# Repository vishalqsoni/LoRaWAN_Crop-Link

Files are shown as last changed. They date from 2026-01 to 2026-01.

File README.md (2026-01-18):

# LoRaWAN_Crop-Link
Crop Link is a LoRa-based IoT data logging and communication system designed for reliable sensor data transmission from remote agricultural fields to the cloud Using LoRaWAN. The system operates independently of GSM or cellular networks.
Screenshot 2026-01-18 at 4 59 33 PM

6F46C575-3EEC-48E3-9C0B-685C3D67DB7D_1_201_a
B4C97D39-0B5F-4EE4-A005-456987E007A9_1_201_a
4F228DE5-FEAE-462C-B5F8-36705A7806EC_1_201_a
C9FC567B-2788-4EFA-AF8E-49FA644E9284_1_201_a
Yes, this project is open source. The circuit contains some mistakes, as this is version 1.1.2, so please do not blindly follow the schematic. For detailed information and updates, please visit my Hackster page.
https://www.hackster.io/iwantmyspace2002/the-crop-link-25cf29

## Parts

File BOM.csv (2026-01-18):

Reference | Qty | Value | DNP | Exclude from BOM | Exclude from Board | Footprint | Datasheet
BT1 | 1 | 18650_cell_holder |  |  |  | LoRa_Link:18650_cell_holder
C1,C2 | 2 | 10 uf C_Polarized |  |  |  | Capacitor_SMD:CP_Elec_4x5.4 | ~
C3,C4,C8,C9,C10,C11 | 6 | 4.7uf |  |  |  | Capacitor_SMD:C_0603_1608Metric | ~
C5 | 1 | 470nf |  |  |  | Capacitor_SMD:C_0603_1608Metric | ~
C6 | 1 | 220nf |  |  |  | Capacitor_SMD:C_0603_1608Metric | ~
C7 | 1 | 100nf |  |  |  | Capacitor_SMD:C_0603_1608Metric | ~
D1 | 1 | 3407A MOSFet |  |  |  | Package_TO_SOT_SMD:SOT-23 | https://www.littelfuse.com/~/media/electronics/datasheets/tvs_diode_arrays/littelfuse_tvs_diode_array_sm712_datasheet.pdf.pdf
D2,D3 | 2 | SS34 |  |  |  | Diode_SMD:D_SMA | https://www.vishay.com/docs/88751/ss32.pdf
D4 | 1 | CHAR |  |  |  | LED_SMD:LED_0603_1608Metric_Pad1.05x0.95mm_HandSolder | ~
D5 | 1 | Done |  |  |  | LED_SMD:LED_0603_1608Metric_Pad1.05x0.95mm_HandSolder | ~
H1,H2,H3,H4 | 4 | MountingHole |  |  |  | MountingHole:MountingHole_2.5mm | ~
J1 | 1 | 1.205volt |  |  |  | Connector_PinHeader_2.54mm:PinHeader_1x02_P2.54mm_Vertical | ~
J2 | 1 | UART1 |  |  |  | Connector_PinHeader_2.54mm:PinHeader_1x04_P2.54mm_Vertical | ~
J3 | 1 | UART0 |  |  |  | Connector_PinHeader_2.54mm:PinHeader_1x04_P2.54mm_Vertical | ~
J4 | 1 | 2171790001 |  |  |  | Connector_USB:USB_C_Receptacle_GCT_USB4105-xx-A_16P_TopMnt_Horizontal | https://www.molex.com/en-us/products/part-detail-pdf/2171790001?display=pdf
J5 | 1 | Conn_01x07_Female |  |  |  | Connector_PinHeader_2.54mm:PinHeader_1x07_P2.54mm_Vertical | ~
J6 | 1 | MJ-179PH |  |  |  | LoRa_Link:12Volt_Socket
J7,J8,J9,J10 | 4 | Conn_01x02 |  |  |  | Capacitor_SMD:C_0201_0603Metric | ~
J11 | 1 | Conn_01x06_Female |  |  |  | Connector_PinHeader_2.54mm:PinHeader_1x06_P2.54mm_Vertical | ~
J12 | 1 | flash |  |  |  | Connector_PinHeader_2.54mm:PinHeader_1x05_P2.54mm_Vertical | ~
J13 | 1 | Conn_01x03_Female |  |  |  | Connector_PinHeader_2.54mm:PinHeader_1x03_P2.54mm_Vertical | ~
J14 | 1 | 532530470 |  |  |  | Connector_PinHeader_2.54mm:PinHeader_1x04_P2.54mm_Vertical
J15 | 1 | Conn_01x04_Female |  |  |  | Connector_PinHeader_2.54mm:PinHeader_1x04_P2.54mm_Vertical | ~
J16 | 1 | Conn_01x05_Female |  |  |  | Connector_PinHeader_1.27mm:PinHeader_1x05_P1.27mm_Vertical | ~
J17 | 1 | Conn_01x04_Male POWER |  |  |  | Connector_PinHeader_2.54mm:PinHeader_1x04_P2.54mm_Vertical | ~
L1 | 1 | 47uh |  |  |  | Inductor_SMD:L_Coilcraft_MSS1210-XXX | ~
R1,R10,R11 | 3 | 10K |  |  |  | Resistor_SMD:R_0603_1608Metric_Pad0.98x0.95mm_HandSolder | ERJPA3F1803V
R2 | 1 | 120E |  |  |  | Resistor_SMD:R_0603_1608Metric_Pad0.98x0.95mm_HandSolder | ERJPA3F1803V
R3 | 1 | 50K |  |  |  | LoRa_Link:50K_preset
R4,R5 | 2 | 2.4E |  |  |  | Resistor_THT:R_Axial_DIN0204_L3.6mm_D1.6mm_P5.08mm_Horizontal | ~
R6,R7 | 2 | 5.1K |  |  |  | Resistor_SMD:R_0603_1608Metric_Pad0.98x0.95mm_HandSolder | ERJPA3F1803V
R8,R9 | 2 | 4.7k |  |  |  | Resistor_SMD:R_0603_1608Metric_Pad0.98x0.95mm_HandSolder | ERJPA3F1803V
SW2 | 1 | SW_Push_DPDT |  |  |  | Button_Switch_THT:DPDT_switch_angled | ~
U1 | 1 | CN3791 |  |  |  | LoRa_Link:cn3763A | CN3763
U2 | 1 | ESP32-S3-WROOM-1 |  |  |  | RF_Module:ESP32-S3-WROOM-1 | https://www.espressif.com/sites/default/files/documentation/esp32-s3-wroom-1_wroom-1u_datasheet_en.pdf
U3 | 1 | Ai-Thinker-Ra-02 |  |  |  | RF_Module:Ai-Thinker-Ra-01-LoRa | http://wiki.ai-thinker.com/_media/lora/docs/c047ps01a1_ra-01_product_specification_v1.1.pdf
U4,U5 | 2 | AP2114H-3.3 |  |  |  | Package_TO_SOT_SMD:SOT-223-3_TabPin2 | http://www.advanced-monolithic.com/pdf/ds1117.pdf

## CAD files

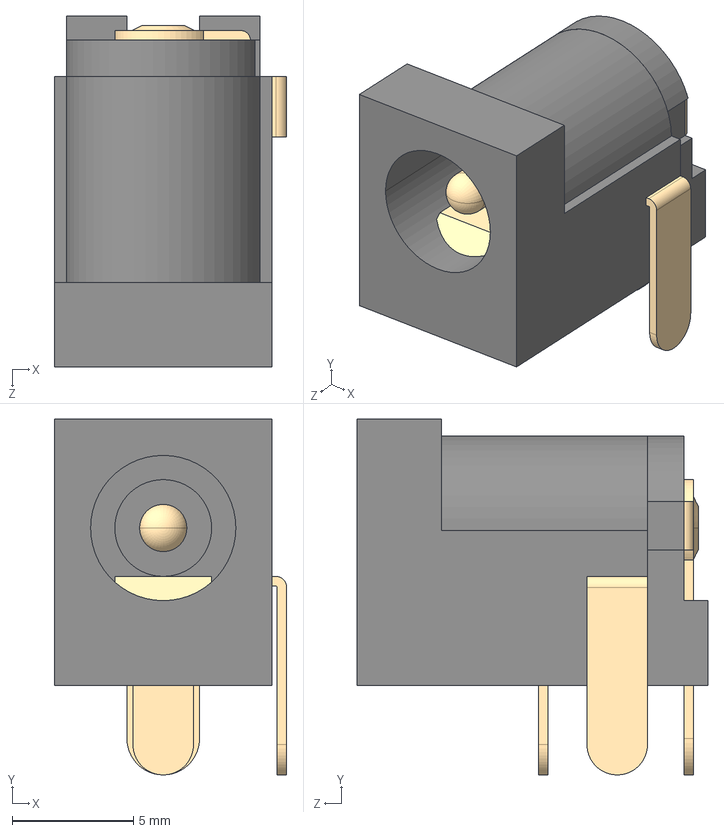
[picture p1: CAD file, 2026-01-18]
Step_files_Crop-Link/12Volt_Socket.step
9.60 x 14.7 x 14.5 mm

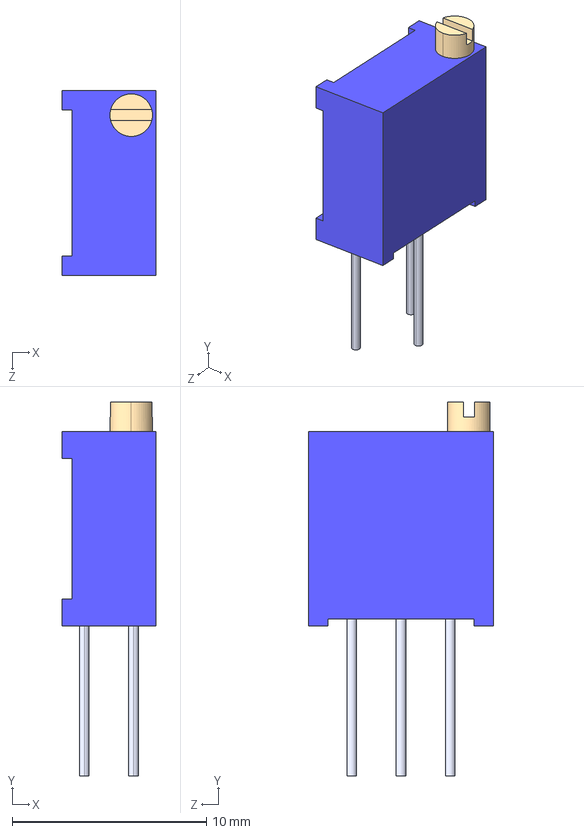
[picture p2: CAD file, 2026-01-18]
Step_files_Crop-Link/50K_preset.step
4.83 x 19.3 x 9.53 mm

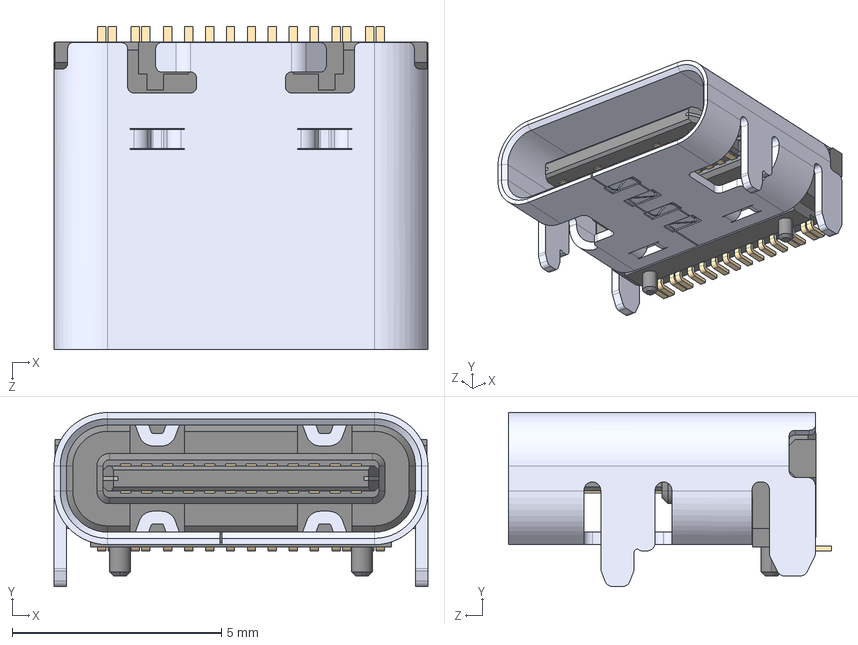
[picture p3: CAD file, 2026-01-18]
Step_files_Crop-Link/C-Type_port.step
8.94 x 4.16 x 7.71 mm

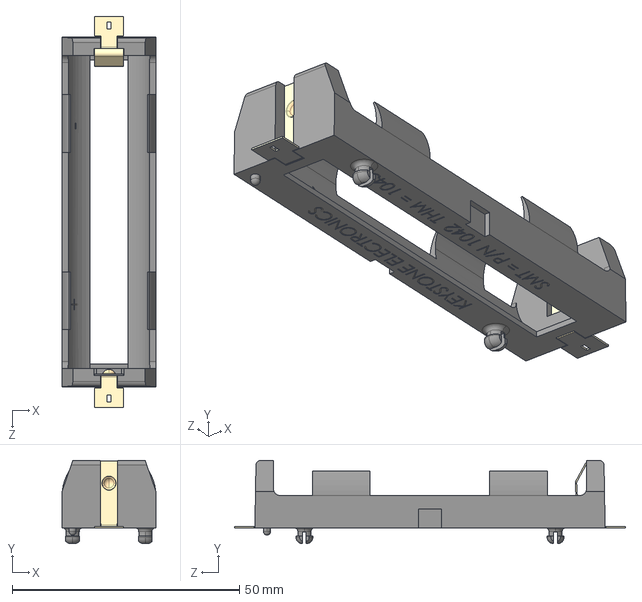
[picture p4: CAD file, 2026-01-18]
Step_files_Crop-Link/18650_cell_holder.step
20.7 x 18.3 x 86.0 mm

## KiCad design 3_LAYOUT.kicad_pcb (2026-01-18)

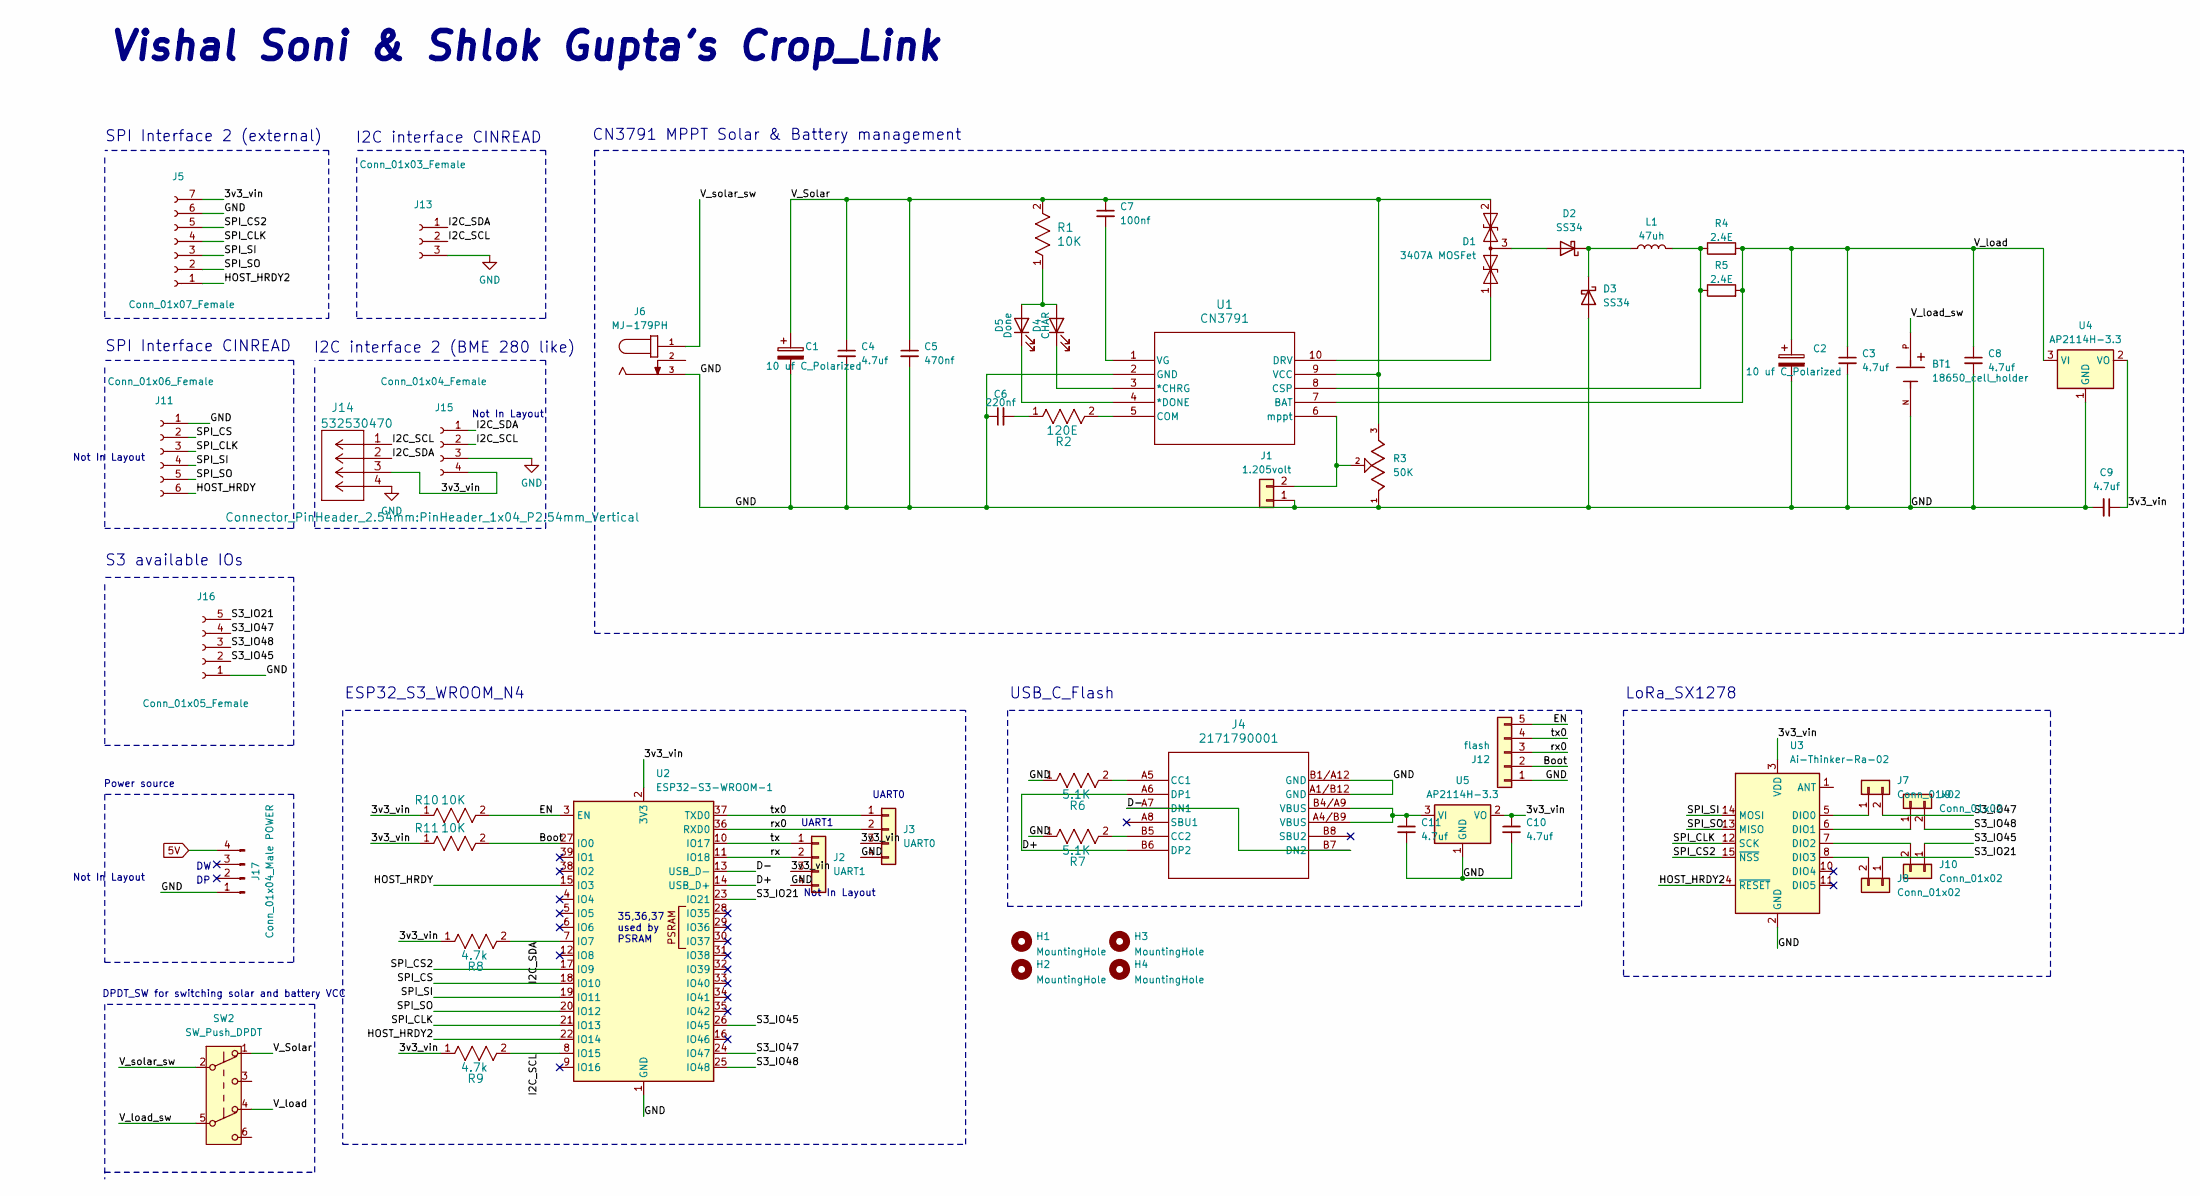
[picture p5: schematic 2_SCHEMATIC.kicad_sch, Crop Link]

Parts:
BT1: 18650_cell_holder; PARTREV E
C1, C2: 10 uf C_Polarized; CP_Elec_4x5.4
C3, C4, C8, C9, C10, C11: 4.7uf; C_0603_1608Metric
C5: 470nf; C_0603_1608Metric
C6: 220nf; C_0603_1608Metric
C7: 100nf; C_0603_1608Metric
D1: 3407A MOSFet; SOT-23
D2, D3: SS34; D_SMA
D4: CHAR; LED_0603_1608Metric_Pad1.05x0.95mm_HandSolder
D5: Done; LED_0603_1608Metric_Pad1.05x0.95mm_HandSolder
H1, H2, H3, H4: MountingHole; MountingHole_2.5mm
J1: 1.205volt; PinHeader_1x02_P2.54mm_Vertical
J2: UART1; PinHeader_1x04_P2.54mm_Vertical
J3: UART0; PinHeader_1x04_P2.54mm_Vertical
J4: 2171790001; USB_C_Receptacle_GCT_USB4105-xx-A_16P_TopMnt_Horizontal
J5: Conn_01x07_Female; PinHeader_1x07_P2.54mm_Vertical
J6: MJ-179PH; 12Volt_Socket; VOLTAGE-RATING 12VDC; FARNELL 1737246
J7, J8, J9, J10: Conn_01x02; C_0201_0603Metric
J11: Conn_01x06_Female; PinHeader_1x06_P2.54mm_Vertical
J12: flash; PinHeader_1x05_P2.54mm_Vertical
J13: Conn_01x03_Female; PinHeader_1x03_P2.54mm_Vertical
J14: 532530470; PinHeader_1x04_P2.54mm_Vertical
J15: Conn_01x04_Female; PinHeader_1x04_P2.54mm_Vertical
J16: Conn_01x05_Female; PinHeader_1x05_P1.27mm_Vertical
J17: Conn_01x04_Male POWER; PinHeader_1x04_P2.54mm_Vertical
L1: 47uh; L_Coilcraft_MSS1210-XXX
R1, R10, R11: 10K; R_0603_1608Metric_Pad0.98x0.95mm_HandSolder
R2: 120E; R_0603_1608Metric_Pad0.98x0.95mm_HandSolder
R3: 50K; 50K_preset; PARTREV 08/19
R4, R5: 2.4E; R_Axial_DIN0204_L3.6mm_D1.6mm_P5.08mm_Horizontal
R6, R7: 5.1K; R_0603_1608Metric_Pad0.98x0.95mm_HandSolder
R8, R9: 4.7k; R_0603_1608Metric_Pad0.98x0.95mm_HandSolder
SW2: SW_Push_DPDT; DPDT_switch_angled
U1: CN3791; cn3763A
U2: ESP32-S3-WROOM-1
U3: Ai-Thinker-Ra-02; Ai-Thinker-Ra-01-LoRa
U4, U5: AP2114H-3.3; SOT-223-3_TabPin2

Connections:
/3v3_vin: C9.1, C10.1, J2.3, J3.3, J5.7, J14.3, J15.4, R8.1, R9.1, R10.1, R11.1, U2.2 (3V3), U3.3 (VDD), U4.2 (VO), U5.2 (VO)
/Boot: J12.2, R11.2, U2.27 (IO0)
/D+: J4.A6 (DP1), J4.B6 (DP2), U2.14 (USB_D+)
/D-: J4.A7 (DN1), J4.B7 (DN2), U2.13 (USB_D-)
/EN: J12.5, R10.2, U2.3 (EN)
/HOST_HRDY: J11.6, U2.15 (IO3)
/HOST_HRDY2: J5.1, U2.22 (IO14), U3.4 (~RESET)
/I2C_SCL: J13.2, J14.1, J15.2, R9.2, U2.8 (IO15)
/I2C_SDA: J13.1, J14.2, J15.1, R8.2, U2.7 (IO7)
/S3_IO21: J8.1, J16.5, U2.23 (IO21)
/S3_IO45: J10.1, J16.2, U2.26 (IO45)
/S3_IO47: J7.2, J16.4, U2.24 (IO47)
/S3_IO48: J9.2, J16.3, U2.25 (IO48)
/SPI_CLK: J5.4, J11.3, U2.21 (IO13), U3.12 (SCK)
/SPI_CS: J11.2, U2.18 (IO10)
/SPI_CS2: J5.5, U2.17 (IO9), U3.15 (~NSS)
/SPI_SI: J5.3, J11.4, U2.19 (IO11), U3.14 (MOSI)
/SPI_SO: J5.2, J11.5, U2.20 (IO12), U3.13 (MISO)
/V_Solar: C1.1, C4.1, C5.1, C7.1, D1.2 (A2), R1.2, R3.3, SW2.1 (A), U1.9 (VCC)
/V_load_sw: BT1.P, SW2.5 (B)
/V_solar_sw: J6.1, SW2.2 (B)
/rx: J2.2, U2.11 (IO18)
/rx0: J3.2, J12.3, U2.36 (RXD0)
/tx: J2.1, U2.10 (IO17)
/tx0: J3.1, J12.4, U2.37 (TXD0)
unnamed: C6.2, R2.1
unnamed: D1.1 (A1), U1.10 (DRV)
unnamed: D1.3 (common), D2.2 (A)
unnamed: D2.1 (K), D3.1 (K), L1.1
unnamed: D4.2 (A), D5.2 (A), R1.1
unnamed: D4.1 (K), U1.3 (*CHRG)
unnamed: D5.1 (K), U1.4 (*DONE)
unnamed: J1.2, R3.2, U1.6 (mppt)
unnamed: J4.A5 (CC1), R6.2
unnamed: J4.B5 (CC2), R7.2
unnamed: J7.1, U3.5 (DIO0)
unnamed: J8.2, U3.8 (DIO3)
unnamed: J9.1, U3.6 (DIO1)
unnamed: J10.2, U3.7 (DIO2)
unnamed: R2.2, U1.5 (COM)
unnamed: L1.2, R4.1, R5.1, U1.8 (CSP)
unnamed: C7.2, U1.1 (VG)
unnamed: C11.1, J4.A4/B9 (VBUS), J4.B4/A9 (VBUS), U5.3 (VI)

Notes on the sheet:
UART0
ESP32_S3_WROOM_N4
USB_C_Flash
35,36,37 used by PSRAM
Not In Layout
S3 available IOs
Power source
SPI Interface CINREAD
Vishal Soni & Shlok Gupta's Crop_Link
CN3791 MPPT Solar & Battery management
UART1
SPI Interface 2 (external)
DPDT_SW for switching solar and battery VCC
I2C interface 2 (BME 280 like)
LoRa_SX1278
I2C interface CINREAD

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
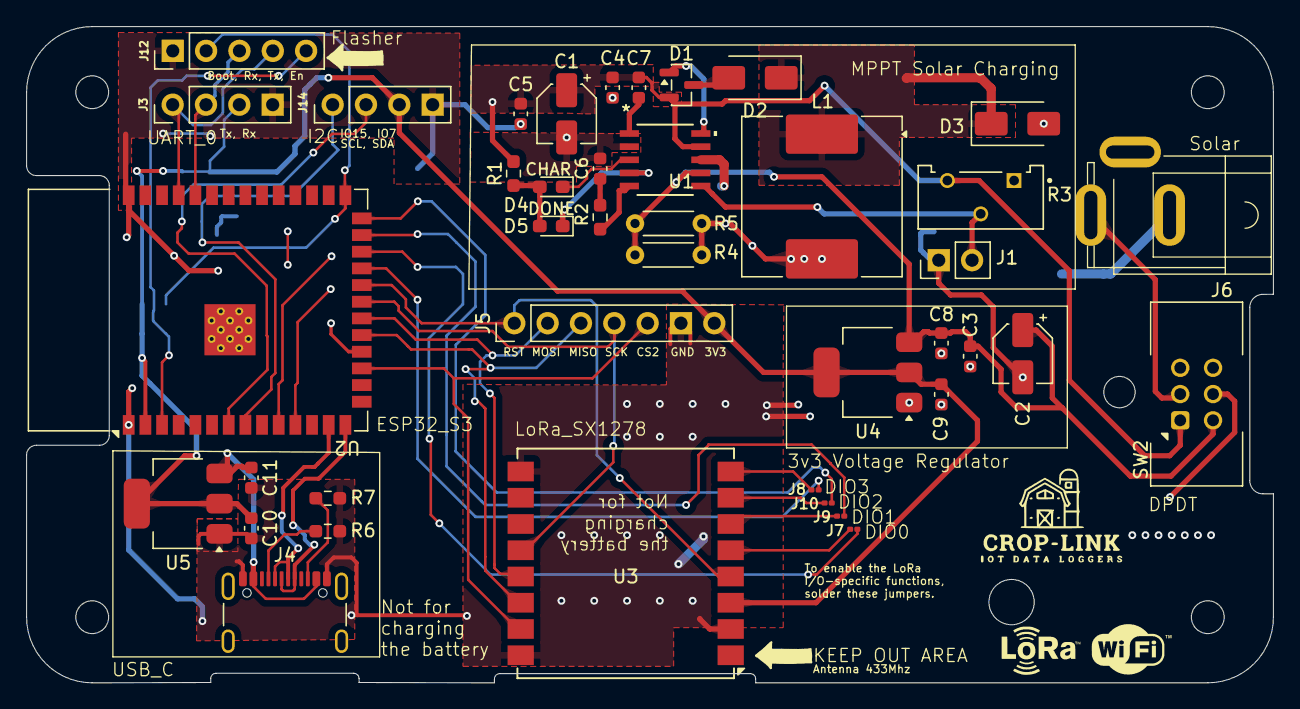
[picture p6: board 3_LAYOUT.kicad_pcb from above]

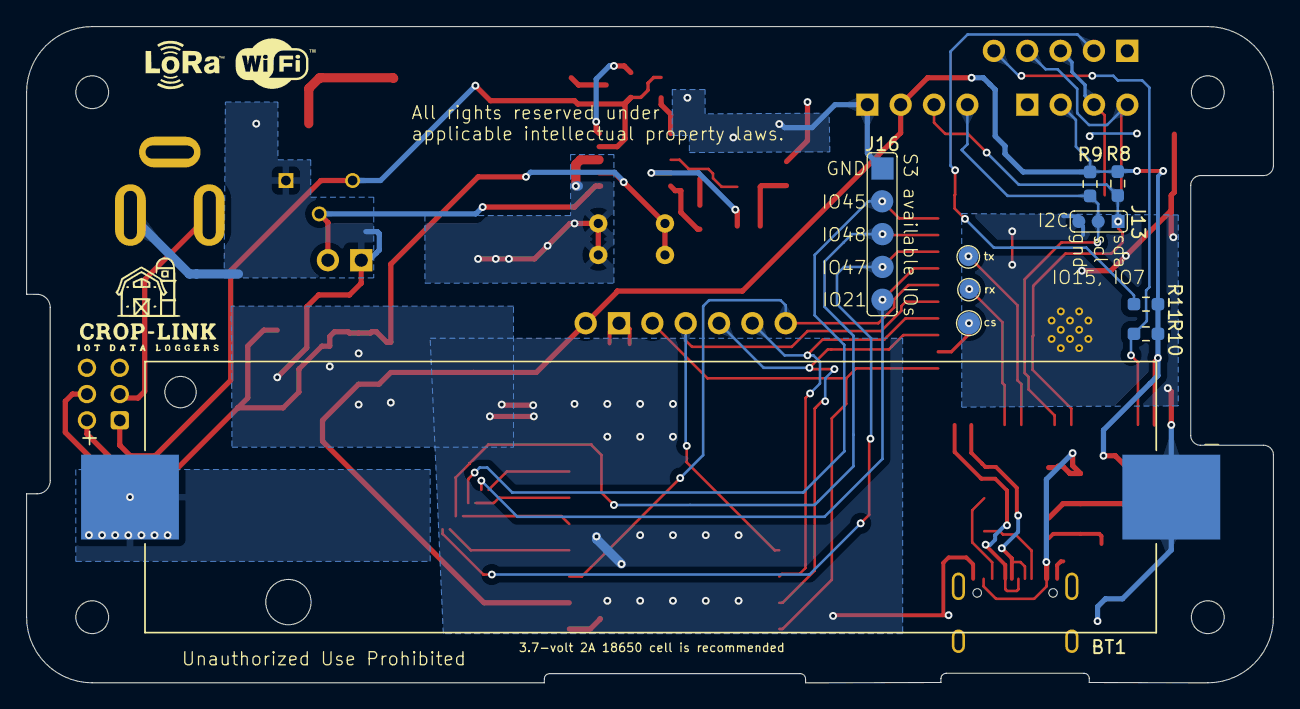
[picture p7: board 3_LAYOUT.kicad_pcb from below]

Board: 2 copper layers, 95.0 x 50.0 mm, 52 parts (7 on the bottom side), 41 nets.

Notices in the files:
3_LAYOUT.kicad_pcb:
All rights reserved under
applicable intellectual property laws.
